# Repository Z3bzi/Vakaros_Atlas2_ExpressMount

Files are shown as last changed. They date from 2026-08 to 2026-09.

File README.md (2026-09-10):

# Vakaros Atlas 2 — Express mast mount

A slide-in cradle for the **aft face** of an Express section mast, screen facing
the cockpit. The Atlas 2 — **in its 2 mm silicone case** — drops in from the top
and lands on a solid ledge; a quarter-turn cam on top retains it. Screen fully
visible, every control reachable with the device locked in.

Orientation: the big raised bar on the screen is at the **bottom**. Facing the
screen, the Atlas's controls are all on the **right** and the lock is on the
**left**.

Generated parametrically — `src/atlas2_mast_mount.py` re-reads
`reference/Mast.step` and `reference/Atlas_2.step` on every run and derives all
mating geometry and cutout positions from them. Nothing is hand-transcribed.

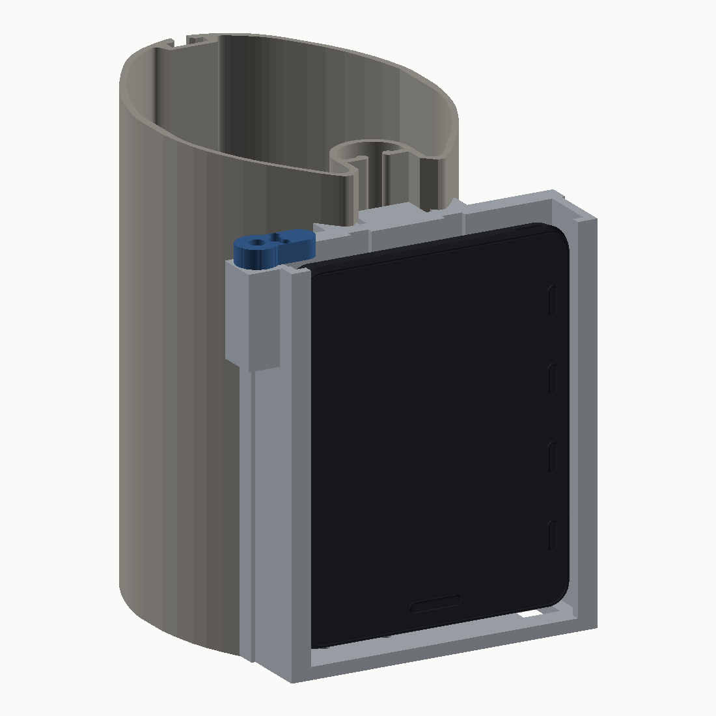
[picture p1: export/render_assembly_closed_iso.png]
assembly


## Load path

Nothing that moves carries the device:

| Direction | Taken by |
|---|---|
| Weight, −Z | **Fixed bottom ledge**, 1138 mm² of bearing area |
| Fore/aft, X | **Fixed side-rail lips** |
| Athwartships, Y | **Fixed side rails** |
| Lift-out, +Z | The rotating lock — a retainer only, never loaded in normal use |

The cradle is a single printed part. The lock is the only moving piece, and it
sees no load unless something tries to throw the device upward.

## Parts

| Part | File | Notes |
|---|---|---|
| Cradle | `export/cradle.step` / `.stl` | One piece: mast tongue, saddle, rails, ledge. 132 cm³ |
| Lock | `export/lock.step` / `.stl` | Quarter-turn cam, 1.2 cm³ |
| Luff nut bar | `export/luff_nut_bar.step` / `.stl` | Preferred — one bar spanning both bolts |
| Luff nut slug | `export/luff_nut_slug.step` / `.stl` | Short single-bolt alternative |
| Assemblies | `export/assembly_*.step` | Named components, see Fusion section |

Cradle 111.0 × 123.7 × 38.8 mm, 145 cm³. Cavity 93.48 × 18.45 × 119.68 mm,
sized for the device plus a 2 mm case plus 0.3 mm fit clearance. The screen sits
**23.75 mm** aft of the mast's aft face.

## The rotating lock, and why it sits where it does

Sliding in from the top creates a hard constraint. The device sweeps a
**removal corridor** — X 71.22…85.57, |Y| ≤ 44.44, everything above Z 57.64 —
plus two narrow channels behind the plate face where its rear protrusions
travel. Anything left in that volume stops the device going in at all,
*whatever it does when locked*. That rules out most of the obvious answers:

- A lever on a mast-normal axis above the device keeps its pivot in the
  corridor at every angle. Dead end.
- Behind the plate face, the gap between the mast (X 63.82) and the rear
  protrusion channels (X 70.06) is **5.7 mm**. A Ø5.2 pivot bore needs about
  11 mm of boss. It does not fit — and a first attempt at a 5 mm blade there
  was severed outright by its own pivot bore.
- A lobe swinging at Y = 0 crosses the mast's aft shoulders, which reach
  X 63.82 at Y ±15.

What does work is **outboard of the device**. On a pad on top of the left-hand
side rail there is no mast and no corridor, so a proper M5 boss fits. Locked,
the lobe reaches inboard over the device's top corner. A quarter turn swings it
fore-and-aft, clear, and the device lifts straight out. It is on the left
because every control on the Atlas is on the right.

The cam pivots on an M5 thumbscrew into a brass insert — nip it up and the cam
is friction-locked. A Ø4.2 hasp hole through the lobe lines up with a hole in
the pad **only in the locked position**, for a pin, seizing wire or a small
padlock.

### The case earns its keep here

The bare Atlas's top edge is a rounded crown — only about 1.8 mm of flat across
its 14.6 mm depth, and 2 mm² of section at the very top (see
`docs/MEASUREMENTS.md`). A cam pressing on that would be point contact on a
curve. The silicone case gives the cam a flat, slightly compliant top face to
work against instead.

The cam sits **0.35 mm** above the cased top, so free lift is **0.40 mm** before
it bites, and it is a face contact rather than a crown contact. The silicone
takes up the rest.

## Mast fixing

The mainsail luff groove measures (see `docs/MEASUREMENTS.md`): outer recess
**20.00 mm** wide and parallel over X 53.4→60.0, throat **5.00 mm**, and a
bolt-rope channel that is a true circle, centre X 50.04, r 10.05.

- The cradle carries a **full-height 19.4 mm tongue** into the parallel recess,
  0.3 mm a side, 6.0 mm of engagement. It takes all the shear and rotation.
- Two **M4** bolts pass through the throat into a half-round bar in the channel.
  They only clamp.
- Saddle wings bear on the aft skin either side of the groove.

> **Below the gooseneck only.** Above it the mainsail bolt rope occupies the
> channel. Site the mount below the sail feeder, and check that lowering the
> main fully does not run the bolt rope down onto the bar.

**M5 will not fit.** Both slots on this section have a throat measuring exactly
5.000 mm, toleranced `5±0.5` on the drawing. An M5 screw has a 5.0 mm major
diameter and cannot pass. M4 gives 1.0 mm clearance nominal.

## Access

Facing the screen, the Atlas's controls are all on the **left**. The lock is on
the right, well clear of them. Verified in the build script, not by eye:

| Feature | Where it lands | Provision |
|---|---|---|
| Screen | — | Front fully open |
| Big raised bar | Bottom of the screen | Front fully open |
| 4 front buttons | Right edge, Y 36.6…39.5 | Side lip stops **3.95 mm** clear |
| Edge control A | **Bottom** edge, Y 34.2…38.0 | Notch through the ledge, open forward |
| Edge control B | **Top** edge, Y 27.2…36.9 | Top is open by design — nothing above it |
| Drainage | — | 2 × Ø4 mm holes in the ledge |

The two edge controls are at opposite ends of the device (one is the power
button, one the charge port). Both get a full opening, so it does not matter
which is which.

## Bill of materials

| Qty | Item |
|---|---|
| 2 | **M4 × 25** A4 stainless socket cap screw (M4 × 30 bottoms out — the bar is 9 mm deep) |
| 2 | M4 A4 washer (Ø9) |
| 1 | Luff nut bar — 90 mm, 3 mm aluminium, tapped M4 at 70 mm centres |
| — | *or* 2 × 25 mm luff nut slug, tapped M4 |
| 1 | M5 × 16 A4 thumbscrew — lock pivot |
| 1 | M5 brass heat-set insert, Ø6.4 × 9.5 mm |
| 1 | Ø4 pin, seizing wire or small padlock for the hasp hole (optional) |
| 1 | 1 mm self-adhesive neoprene/EVA pad, ~90 × 115 mm (optional, kills the 0.4 mm lift) |

The luff nut is a circular segment sized r 9.70 against the channel's r 10.05,
flat face at X 49.30. Make it from metal — printed threads will not hold here.
It feeds in from the open end of the groove; it cannot be toggled through a
5 mm throat.

## Printing

PETG, ASA or nylon. PLA will creep and go brittle in UV — not on a mast.

| | Cradle | Lock |
|---|---|---|
| Orientation | Standing on its bottom edge (mast axis vertical) | Flat |
| Support | None — tongue, rails and saddle are vertical extrusions | None |
| Bed | Brim recommended | — |
| Perimeters | 5 | 4 |
| Infill | 40 % gyroid | 60 % |
| Layer | 0.2 mm | 0.15 mm |

Standing the cradle on its bottom edge runs the tongue, rails and saddle as
straight vertical extrusions and puts the layer lines across the ledge's
bending direction.

## Assembly

1. Print both parts. Melt the M5 insert into the lock pad from above.
2. Feed the luff nut bar into the mainsail groove from its open end and slide it
   to the height you want, **below the gooseneck**.
3. Offer the cradle up so its tongue enters the recess, and run in the two
   M4 × 25 screws with washers. The heads sit in counterbores, flush with the
   plate face. The tongue should feel snug before you tighten.
4. Optional: stick the neoprene pad to the ledge.
5. Fit the lock with its M5 thumbscrew. It should turn firmly, not freely.
6. To load: turn the lock fore-and-aft, slide the Atlas down between the rails —
   screen aft, big raised bar at the bottom, controls to the right, rear
   protrusions into the relief channels — until it lands on the ledge. Turn the lock inboard over the top corner and
   nip up the thumbscrew. Add a pin or seizing wire through the hasp if you want
   it positively locked.

## Opening in Fusion 360

Use the **STEP** files. `assembly_mount_only.step` and
`assembly_with_mast_and_device.step` carry STEP product structure, so they
arrive as **named components** (`cradle`, `lock`, `luff_nut_bar`, plus
`mast_express` and `atlas_2`), coloured and positioned. Fusion applies joints to
components, never to loose bodies.

If the model comes in lying on its side, check **Preferences → Default modeling
orientation** — these files are Z-up, mast axis on +Z.

Everything is already assembled, so use **As-built Joints**
(`Assemble → As-built Joint`); a normal Joint moves parts to mate them.

| Pair | Joint | How |
|---|---|---|
| `cradle` → ground | — | Right-click → **Ground** |
| `lock` ↔ `cradle` | **Revolute** | As-built Joint, Motion = Revolute, click the Ø5.3 pivot bore |
| `luff_nut_bar` ↔ `cradle` | **Rigid** | As-built Joint, Motion = Rigid |
| `atlas_2` ↔ `cradle` | **Slider** | As-built Joint, Motion = Slider, Z axis — that is how it loads |
| `mast_express` → ground | — | **Ground** it |

Lock pivot axis: **X = 79.0, Y = −53.5**, parallel to Z. Joint limits 0° to 90°.

## Rebuilding

```
pip install cadquery
python3 src/atlas2_mast_mount.py     # writes export/*.step and *.stl
python3 src/render.py                # writes export/render_*.png
```

The build self-checks on every run and prints `ALL CHECKS PASSED` or the list of
failures. It asserts:

- zero interference between cradle, lock, luff bar, mast and device
- the tongue and saddle actually seat on the mast rather than floating
- the cradle is clear of the device's true swept removal corridor
- the device slides in from the top over 0–120 mm without touching
- the lock swings fully clear when open, and which way it has to turn
- free lift under the closed lock, and that it resists a 1 mm lift
- bearing area of the load-bearing ledge
- clear access below the bottom edge control, above the top edge control, and
  in front of the four front buttons
- that a box of device + 2 mm case dimensions fits the cavity
- each part is a single valid solid with no loose fragments, and every exported
  STEP re-imports as one solid with zero volume change

## Caveats

- **Below the gooseneck only** — see the mast fixing note.
- `Atlas_2.step` is Vakaros's *simplified* model. Feature positions are solid,
  small details are approximate. Test-fit before a final print.
- The throat is toleranced `5±0.5`. Check your own extrusion with a caliper.
- Tongue and saddle are cut from the section as-measured with 0.5 mm clearance.
  A different extrusion batch, or anodising build-up, may need `CLR_MAST` or
  `TONGUE_HALF_W` opening up.
- **The cavity is sized for the device in its 2 mm silicone case.** Without the
  case it will be loose by 2 mm a side. Change `CASE_T` in the build script if
  you run it bare or in a different case.
- A mount on the aft face adds windage and weight aloft on the sail's leeward
  side. Keep it as low on the spar as sightlines allow.

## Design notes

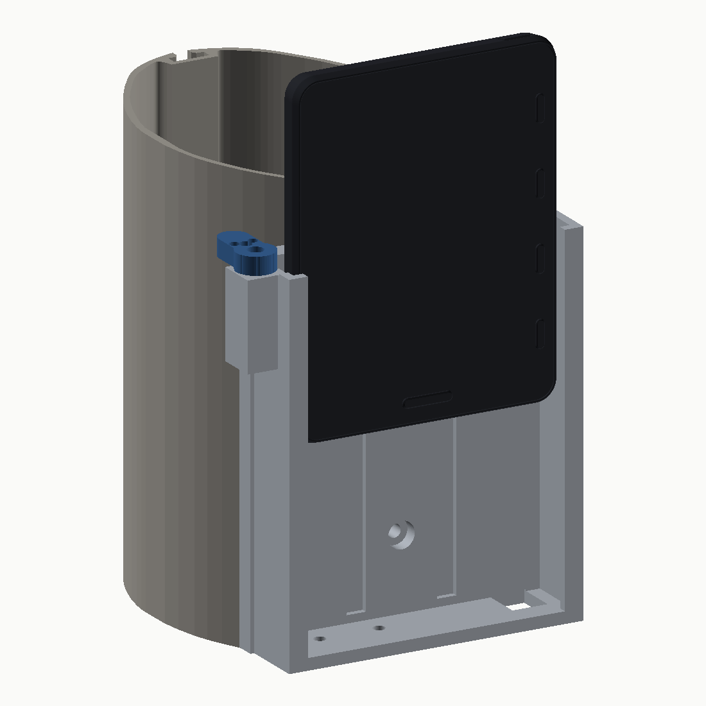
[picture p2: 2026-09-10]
export/render_slide_in_iso.png

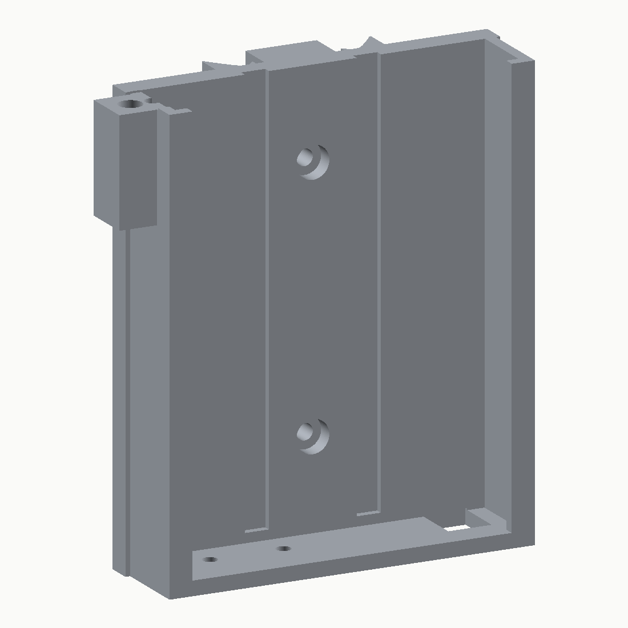
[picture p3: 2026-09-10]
export/render_cradle_front.png

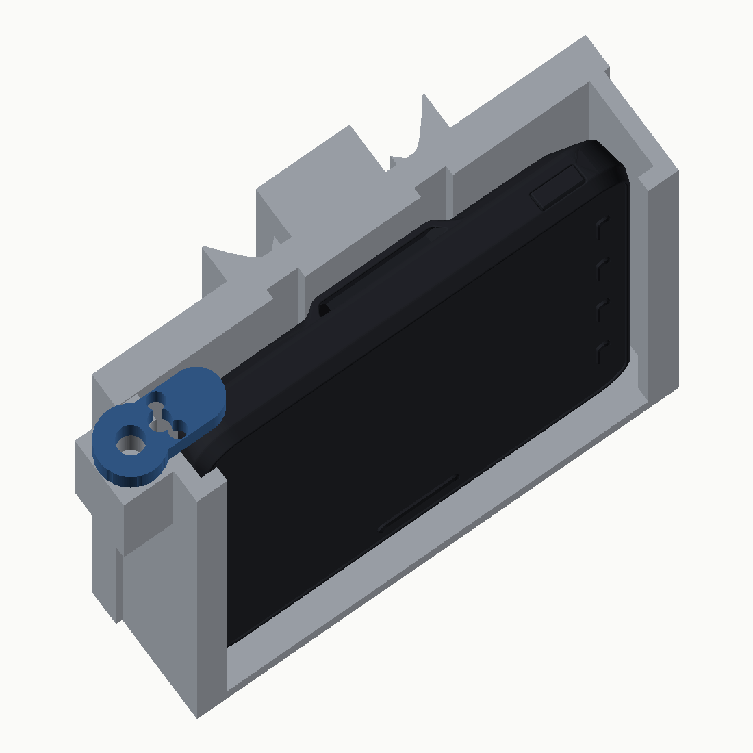
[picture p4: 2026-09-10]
export/render_lock_detail_top.png

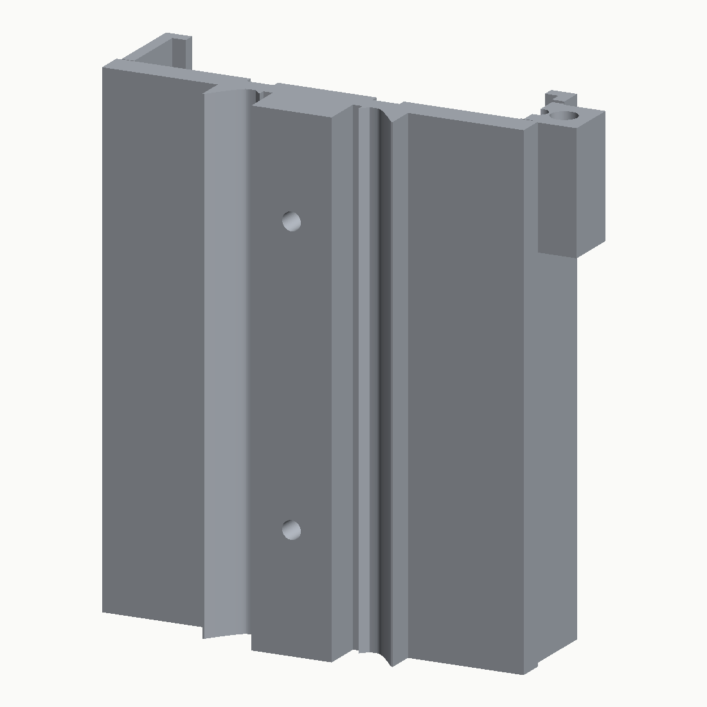
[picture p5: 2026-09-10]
export/render_cradle_tongue.png

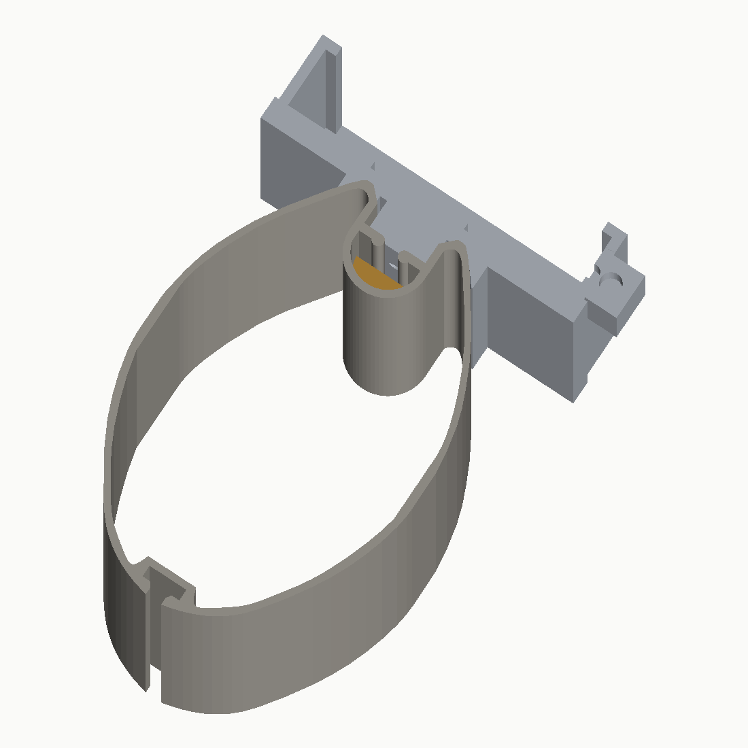
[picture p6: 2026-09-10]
export/render_groove_detail_top.png

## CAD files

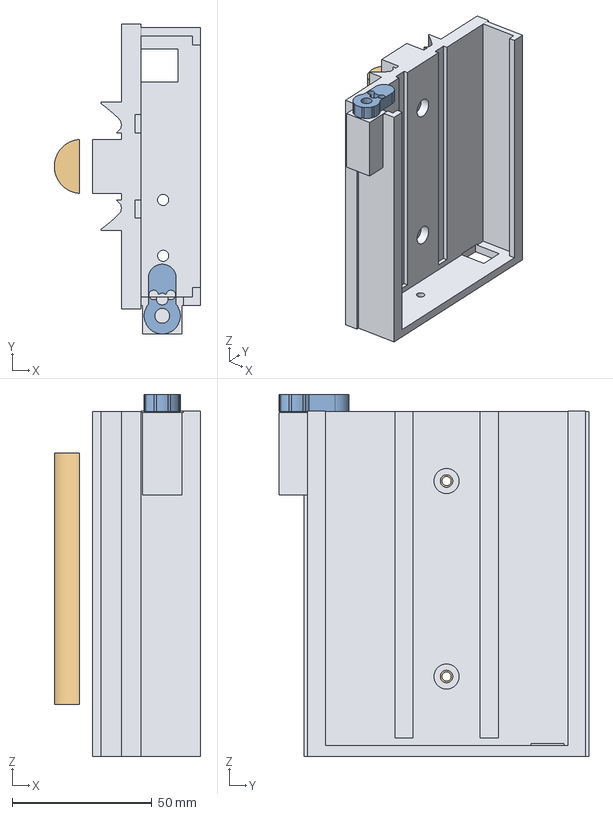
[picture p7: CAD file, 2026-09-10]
export/assembly_mount_only.step
52.4 x 111.0 x 129.6 mm
cradle
lock
luff_nut_bar

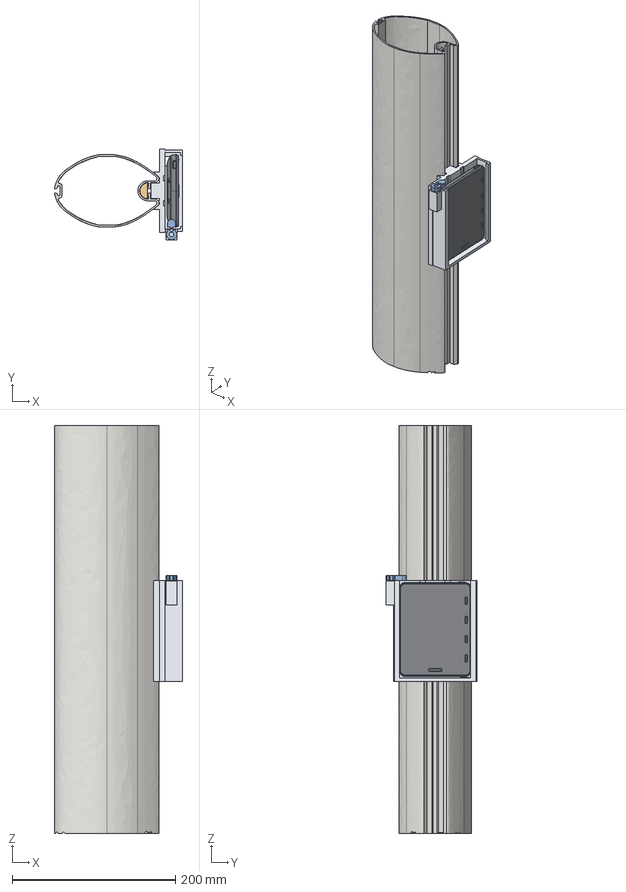
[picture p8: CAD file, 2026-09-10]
export/assembly_with_mast_and_device.step
157.5 x 111.0 x 500.0 mm
cradle
lock
luff_nut_bar
mast_express
atlas_2

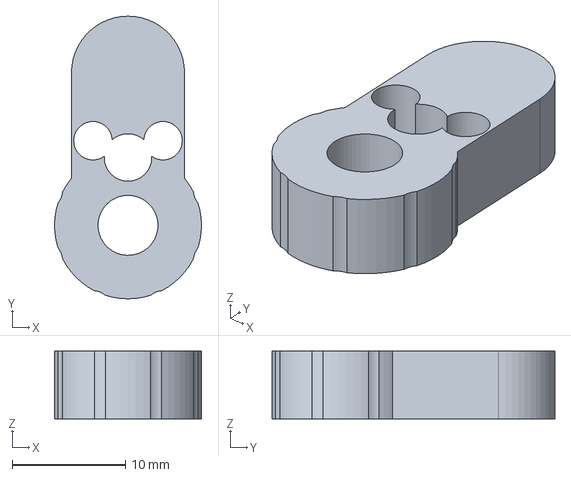
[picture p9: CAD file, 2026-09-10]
export/lock.step
13.0 x 25.0 x 6.00 mm

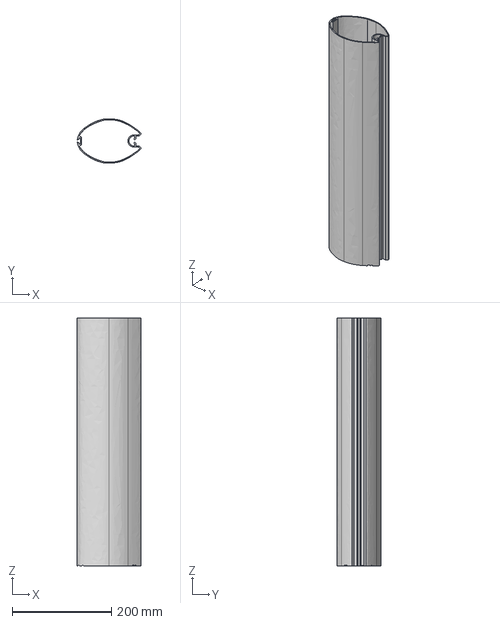
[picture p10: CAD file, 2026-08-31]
reference/Mast.step
128.5 x 89.2 x 500.0 mm

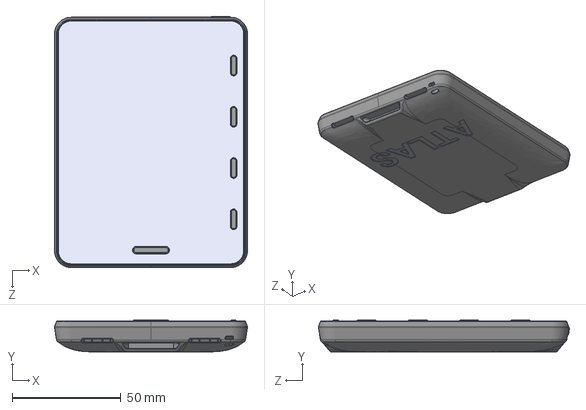
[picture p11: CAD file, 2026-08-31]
reference/Atlas_2.step
88.9 x 14.6 x 115.7 mm

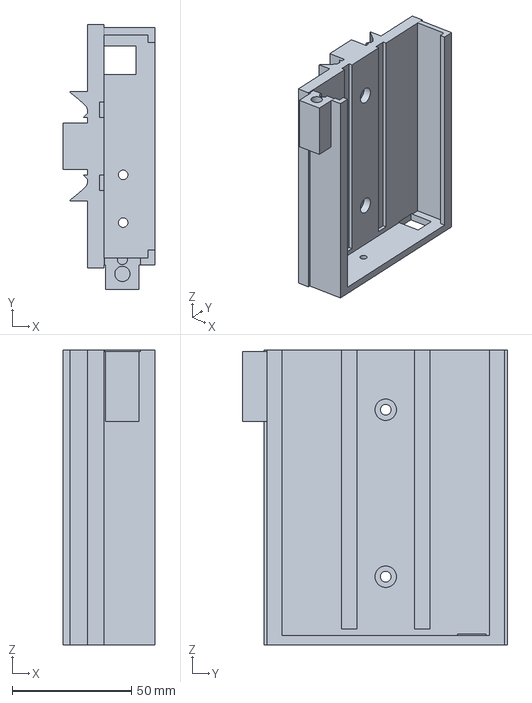
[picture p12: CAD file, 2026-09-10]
export/cradle.step
38.8 x 111.0 x 123.7 mm

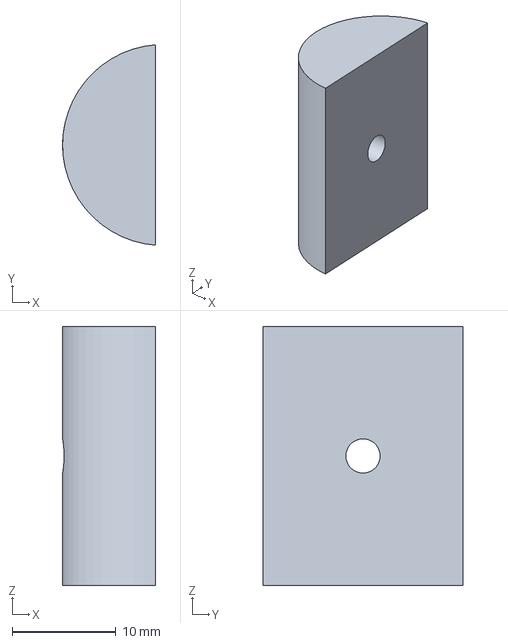
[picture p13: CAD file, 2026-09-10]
export/luff_nut_slug.step
8.96 x 19.3 x 25.0 mm

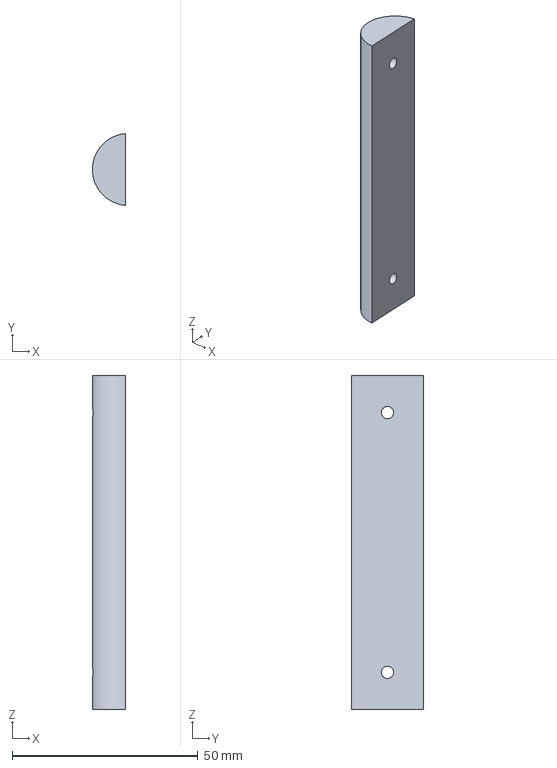
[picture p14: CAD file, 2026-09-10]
export/luff_nut_bar.step
8.96 x 19.3 x 90.0 mm

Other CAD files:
export/cradle.stl
export/lock.stl
export/luff_nut_bar.stl
export/luff_nut_slug.stl

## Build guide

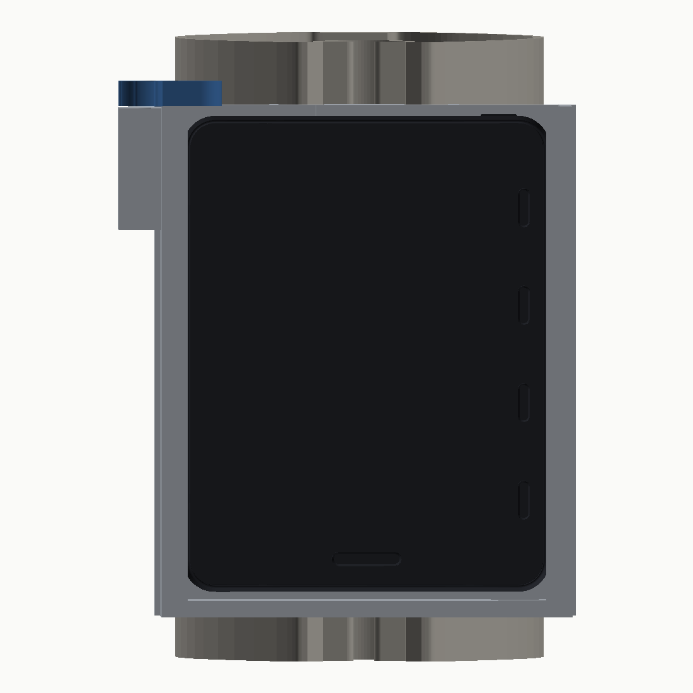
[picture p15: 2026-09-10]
export/render_assembly_closed_front.png

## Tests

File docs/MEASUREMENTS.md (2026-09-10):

# Measured geometry

Everything below was extracted from the two supplied STEP files with OpenCASCADE
(`src/atlas2_mast_mount.py` re-derives the mast profile at build time, so the
mount tracks the CAD rather than these notes). Nothing is taken from the
scanned Express section drawing — that drawing was only used to confirm the
result looked sane.

## Units

| File | Declared units | Note |
|---|---|---|
| `Mast.step` | millimetre | Autodesk / ST-Developer, AP214 |
| `Atlas_2.step` | **inch** (`CONVERSION_BASED_UNIT('INCH')`) | SolidWorks 2022, "Atlas 2_SIMPLIFIED" |

`Atlas_2.step` mixes inch and metre unit contexts, so a naive text parse of its
`CARTESIAN_POINT`s gives nonsense (a 36 m bounding box). It must be read
through a real STEP reader.

## Mast — Express section

Straight extrusion along Z, hollow, symmetric about Y = 0.

| Quantity | Value |
|---|---|
| Section envelope | 128.52 (X, chord) × 89.21 (Y) mm |
| Forward-most point (nose) | X = **−64.700** |
| Aft-most point (sail track) | X = +63.823 |
| Half width | Y = ±44.606 |
| Wall (at the nose) | ≈ 4.9 mm |

Drawing says 130 × 90; the solid measures 128.5 × 89.2. The drawing figures are
to the theoretical sharp corners.

### Forward T-slot (accessory track — not used by the current mount)

Traced off the section at Z = 250:

| Feature | Value |
|---|---|
| Throat (mouth) width | **5.000 mm** (Y = ±2.500) |
| Throat depth, parallel portion | X = −64.7 → −62.5 |
| Flare | ≈ 34° out to X = −61.0 |
| Bearing shoulder | X = **−61.000**, Y = ±3.520 … ±6.000 |
| Internal channel width | **12.000 mm** (Y = ±6.000) |
| Channel floor | X = **−57.500** (channel is 3.5 mm deep) |
| Total slot depth from the nose | 7.16 mm |

This matches the drawing's `5±0.5` throat callout. It is a flat rectangular
track, i.e. a fitting/accessory slot. The mount used it up to commit `8bc21e8`;
it now mounts aft instead, so the screen faces the cockpit.

### Aft mainsail luff groove (what the mount now bolts into)

Rasterised as solid material from the section at Z = 250:

| Feature | Value |
|---|---|
| Aft-most point of the section | X = **63.822**, at Y ≈ ±15 |
| Recess mouth | X = 63.5, Y = ±13.52, **flared — no undercut** |
| Recess, parallel portion | **20.000 mm** wide (Y = ±10.000), X = 53.4 … 60.0 |
| Recess shoulder (tongue stops here) | X = **53.496** |
| Throat, narrowest | **5.000 mm**, at X = 52.0 |
| Throat extent | X ≈ 49.7 … 53.4 |
| Bolt-rope channel | circle, centre X = **50.04**, r = **10.05** (Ø20.1) |
| Channel usable face | X ≈ 49.3 forward |

Circle fit residual across six measured points is under 0.1 mm, so the channel
is a true Ø20 circular bore.

The clear opening at each depth:

| X | 63.5 | 62.0 | 60.0 | 56.0 | 53.5 | 53.0 | 52.0 | 50.5 | 49.0 | 45.0 | 41.5 |
|---|---|---|---|---|---|---|---|---|---|---|---|
| width | 27.03 | 24.03 | 20.02 | 20.00 | 20.00 | 6.03 | **5.01** | 5.95 | 20.00 | 17.62 | 10.60 |

Two consequences drove the design:

1. The **20.00 mm parallel recess** is a genuine location feature, so the back
   plate carries a full-height 19.4 mm tongue that takes all the shear and
   rotation. The bolts only clamp.
2. The mouth **flares outward**, so there is nothing to hook onto from
   outside — the fixing has to reach through the 5.00 mm throat into the round
   channel. Hence a half-round bar that drops in from the end of the groove.

Note both slots on this section have a 5.00 mm throat, so the M4 decision
below applies either way.

## Vakaros Atlas 2

8 solids. Device axes: **Xa** across, **Ya** thickness (+Ya = screen side),
**Za** height.

| Quantity | Value |
|---|---|
| Overall | 88.89 (Xa) × 15.76 (Ya) × 115.66 (Za) mm |
| Body | Xa ±44.44, Ya −14.41 … +1.00, Za ±57.64 |
| Front bezel plane | Ya = +1.00 |
| Cover glass | Ya ≈ −0.55, Xa ±42.70, Za ±55.90 |
| **Flat rear plateau** | Ya = **−13.25**, Xa ±25.20, Za ±51.81 |
| Rear-most feature | Ya = −14.41 |

### Feature positions

| Feature | Xa | Ya | Za |
|---|---|---|---|
| Button 1 (front) | 36.61 … 39.49 | −1.79 … **+1.35** | 29.70 … 41.10 |
| Button 2 (front) | 36.61 … 39.49 | −1.79 … +1.35 | 6.10 … 17.50 |
| Button 3 (front) | 36.61 … 39.49 | −1.79 … +1.35 | −17.50 … −6.10 |
| Button 4 (front) | 36.61 … 39.49 | −1.79 … +1.35 | −41.10 … −29.70 |
| Top-centre bar (logo/status) | ±9.70 | −1.79 … +1.35 | 47.91 … 51.29 |
| **Power button (top edge)** | 34.19 … 38.04 | −5.91 … −7.62 | at Za ≈ +57 |
| **Charge port (bottom edge)** | 27.21 … 36.94 | −1.86 … −5.82 | Za ≈ −58.01 |
| Rear protrusion A | −17.03 … −13.16 | to −14.41 | 34.40 … 55.69 |
| Rear protrusion B | 13.16 … 17.03 | to −14.41 | −55.69 … −34.40 |

Three things here differ from the layout assumed in the original plan:

1. **The four buttons are on the FRONT face**, in a column ~5 mm in from the
   right-hand edge — they are not side buttons. They stand 0.35 mm proud of the
   bezel, making them the front-most feature on the device.
2. **The power button is on the top edge but offset to one side** (Xa 34…38),
   not centred, and it sits toward the rear of the thickness.
3. **The charge port is on the bottom edge**, offset to the *same* side as the
   buttons (Xa 27…37).

So all of the controls plus the charge port are grouped at one end of the
device (+Xa). The two rear protrusions stand 1.16 mm proud of the flat rear
plateau and must be relieved, or the device rocks.

## Derived stack

| | X (world) |
|---|---|
| Mast nose | −64.70 |
| Saddle inner face (nose + 0.4 clearance) | −65.10 |
| Back-plate front face / parting plane | **−73.10** |
| Device rear plateau | −73.10 |
| Device front bezel | −87.35 |
| Shell lip inner face | −87.55 |
| Shell front face | −90.55 |

Total standoff, mast nose to screen: **22.65 mm**.

## Atlas 2 top edge — why retention is a crown contact

The slide-in design retains the device with a cam pressing on its top edge, so
how flat that edge is matters. Measured as horizontal section area of the device
in 4 mm wide Y bands, across its full 14.6 mm depth (58.4 mm² would be fully
flat):

| Y band | Z = 57.50 | 57.20 | 56.80 | 56.00 |
|---|---|---|---|---|
| 0…4 | 7.1 | 18.0 | 32.5 | 32.7 |
| 16…20 | 7.1 | 18.0 | 31.6 | 28.8 |
| 32…36 | 7.1 | 18.0 | 32.5 | 32.6 |
| 38…42 | 0.2 | 2.7 | 9.3 | 24.6 |
| 42…46 | 0.0 | 0.0 | 0.0 | 0.0 |

At the very top (Z = 57.64) there is only **2.0 mm²** of section across the whole
device. The top is a rounded crown, about 1.8 mm of flat across a 14.6 mm depth,
and it rolls off hard past Y ≈ 38.

Consequence: no retainer pressing from above can get a large contact patch. The
cam is set 0.35 mm above the crown, giving 0.40 mm of free lift before it bites.
That stops the device leaving — the rails constrain every other direction — but
it is point contact on a curve, not a flush clamp.

## The removal corridor

Because the device now loads from the top, the volume it sweeps on the way in
is a hard constraint on where anything can live:

| Region | Extent |
|---|---|
| Main body | X 71.22…85.57, \|Y\| ≤ 44.44, Z above 57.64 |
| Rear protrusion channels | X 70.06…71.22, \|Y\| 13.16…17.03, Z above 57.64 |

Anything in that volume blocks insertion regardless of what it does when
locked. Behind the plate face the usable gap between the mast (X 63.82) and the
protrusion channels is only **5.7 mm** — too narrow for a pivot boss, which is
why the lock ended up outboard on the rail pad.

## Orientation

The device is mounted with its **+Za end downward**: the big raised bar on the
front face (Xa ±9.70, Za 47.91…51.29) sits at the bottom of the screen. The
transform is therefore

    Xw = Ya + DEV_CX ,  Yw = +Xa ,  Zw = −Za

a 180° rotation about the device's own Ya axis (the screen normal), then −90°
about Z. Determinant +1, so it is a rotation and not a mirror.

Where the features land, with the 2 mm case (`DEV_CX` = 86.472):

| Feature | Y | Z | X |
|---|---|---|---|
| Big raised bar (screen) | −9.70…9.70 | **−51.29…−47.91** | 84.68…87.82 |
| Edge control A | 34.19…38.04 | **−57.02…−54.19** (bottom) | 78.85…80.56 |
| Edge control B | 27.21…36.94 | **55.30…58.01** (top) | 80.65…84.61 |
| 4 front buttons | 36.61…39.49 | −41.10…−29.70 | 84.68…87.82 |
| Rear protrusion pair | ±13.16…17.03 | ±34.40…55.69 | 72.06…77.46 |

Everything the user touches is on **+Y**, which is the viewer's right when
facing the screen. That is why the lock went to −Y.

## Silicone case

The Atlas 2 is carried in a 2 mm silicone case, so the cradle is built around an
envelope of the device grown by `CASE_T` = 2.0 on every face, plus the usual
0.3 mm fit clearance:

| | Bare device | Envelope |
|---|---|---|
| Half width | 44.44 | **46.44** |
| Top / bottom | ±57.64 | **±59.64** |
| Back → front (Ya) | −13.25 … +1.00 | **−15.25 … +3.00** |
| Depth | 14.25 mm | **18.25 mm** |

Two knock-on effects worth noting. The rear protrusions stand 1.16 mm proud of
the device's rear plateau; a case following that contour bulges the same amount,
so the 2 mm relief channels are still required. And the cam now bears on the
flat top of the case rather than the device's rounded crown, which is a much
better contact — see the README.

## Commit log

2026-08-31 Add parametric Atlas 2 mast mount for Express section
    Two printed parts that bolt into the mast's forward T-slot and hold a
    Vakaros Atlas 2 in a hinged, thumbscrew-locked clamshell. All mating
    geometry is derived at build time from the supplied STEP files rather
    than transcribed, so the parts track the CAD.
    Parts: back plate (conforming mast saddle + device backing), front shell
    (clamshell with side retaining lips), toggle nut and slide nut bar for
    the mast slot, and a thumbscrew knob.
    Three measured findings drove changes from the original plan:
    - The forward T-slot throat is exactly 5.000 mm (drawing tolerances it
    5+/-0.5), so an M5 screw cannot pass it. Uses M4, which also gives
    0.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
    [Atlas_2.step, Mast.step, assembly_mount_only.step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]
2026-08-31 Export assemblies with named STEP components for Fusion
    The assembly STEPs were written as a flat compound, so they imported as
    three unnamed bodies. Fusion 360 can only apply joints to components,
    never to loose bodies, which made the assemblies awkward to use.
    Export them through cadquery's Assembly instead, so they carry STEP
    product structure and per-part colour. They now import as named,
    separately selectable components: back_plate, front_shell, toggle_nut,
    and for the in-situ file also mast_express and atlas_2.
    Also document the Fusion workflow in the README, including the hinge
    axis position and the verified 0-120 degree joint limits.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
    [assembly_mount_only.step, assembly_with_mast_and_device.step, back_plate.step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]
2026-08-31 Move the mount to the mast's aft face, in the mainsail luff groove
    The mount was on the forward face, which pointed the screen at the bow —
    unreadable from the cockpit. It now mounts aft so the screen faces the
    crew.
    Rasterising the section as solid material showed what the aft face
    actually offers: an outer recess 20.000 mm wide and parallel over
    X 53.4-60.0, a 5.000 mm throat, and a bolt-rope channel that is a true
    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
    [assembly_mount_only.step, assembly_with_mast_and_device.step, back_plate.step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]
2026-09-10 Rebuild as a slide-in cradle with a quarter-turn lock
    Replaces the hinged clamshell. The Atlas 2 now drops in from the top and
    lands on a solid ledge that is part of the cradle body, so nothing that
    moves carries it: weight goes to the fixed ledge (1156 mm2 of bearing
    area), fore/aft to the fixed rail lips, athwartships to the fixed rails.
    The rotating lock only resists lift-out. The clamshell, hinge and two
    thumbscrews are gone; the cradle is a single printed part.
    Loading from the top turned out to be the constraint that drove the whole
    design. The device sweeps a removal corridor - X 71.22-85.57, |Y| <=
    44.44, everything above Z 57.64, plus two narrow channels behind the
    plate face where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
    [assembly_mount_only.step, assembly_with_mast_and_device.step, back_plate.step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]
2026-09-10 Flip the device the right way up and size the cavity for the 2 mm case
    The Atlas was mounted upside down: the big raised bar on the screen is
    the bottom of the device, not the top. The transform is now a 180
    rotation about the device's own screen normal followed by the existing
    -90 about Z, so Xw = Ya + CX, Yw = +Xa, Zw = -Za. Determinant is +1, so
    it is a rotation and not a mirror.
    That flip moves everything. Both edge controls swap ends - the one that
    was on the top edge is now on the bottom and needs a notch through the
    ledge, and the one that was on the bottom is now on the top, where the
    cradle is already open. All four front buttons and both edge controls
    end up on +Y, so the rotating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
    [assembly_mount_only.step, assembly_with_mast_and_device.step, cradle.step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]
